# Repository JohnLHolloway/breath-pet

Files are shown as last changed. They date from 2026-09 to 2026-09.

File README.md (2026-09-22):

# Breath Pet

A pocket party aquarium for the **LILYGO T-Display-S3**. Pick a nickname, adopt a pet, and watch everyone's creatures swim around together. Wake them with an MQ-3 sample or a quick bubble game, collect silly outfits, and decorate the shared tank.

| The shared tank | Your pet and its belongings |
| --- | --- |
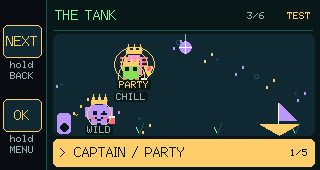
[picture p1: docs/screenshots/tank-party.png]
Three pets swimming with accessories and status labels
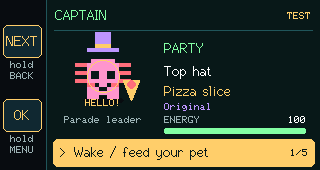
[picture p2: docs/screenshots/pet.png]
Pet detail with personality, outfit and one energy meter
|  |  |

**MQ-3 readings produce fictional game levels, not BAC or an estimate of intoxication.** A cup-vapor test works for setup without drinking. Clothes and rewards do not depend on getting a higher reading.

## Start playing

1. Hold the board landscape with **USB and the two front buttons on the left**.
2. Select **Add a pet**, pick a nickname, then a species. The tank starts empty and holds up to six pets.
3. Select your pet. **Wake / feed** starts a **5-second countdown**, then **10 seconds of BLOW**. Only the highest reading during BLOW determines the game reaction.
4. Watch its state in the tank, or open its detail page for History, Take a nap, Wardrobe and Play bubble catch.

Clean air is monitored in the background. Feed starts immediately when the signal is settled; **Sensor recovering** appears only if it needs more time. It starts the countdown automatically once ready, or you can cancel. The first window after power-up takes at least ten seconds. For cup testing, bring vapor near the dry sensor at BLOW and remove it when capture finishes.

| Physical button | Tap | Hold 1.2 seconds |
| --- | --- | --- |
| **Upper / BOOT / GPIO0** | NEXT: cycle the selection | Back / cancel |
| **Lower / GPIO14** | OK: choose the gold action | Evening menu |

The left rail corresponds to the physical buttons. Every selectable page uses the same gold action bar. During countdown and BLOW, taps are disabled; holds still cancel or open the menu. No touch controller was detected on the tested board; both buttons are sufficient. LILYGO sells standard and touch variants. Touch-controller support exists in firmware but has not been verified on touch hardware.

## What the pets do

- **CHILL, PARTY and WILD** change swimming and expressions. High readings cause no damage.
- After **10 powered minutes** without feeding or a completed game, pets become DROWSY; after **20**, they fall ASLEEP. Any completed sample, even level zero, or a three-catch game wakes them. There is one energy meter.
- Check in to find red cups, hats and other accessories, with at most one rewarded check-in per pet per ten powered minutes. Clothes and colours are collected during the current evening.
- Everyone contributes to a jukebox, pirate ship and disco ball. View Best Dressed, Most Naps and Social Butterfly in Evening awards.
- **Start new evening** asks for confirmation, then clears pets, readings, clothes, colours, awards progress and shared decorations. Sensor settings stay saved.

See the [gameplay guide](docs/GAMEPLAY.md) for reactions, rewards, persistence and all menu options, or browse the [current screen gallery](docs/screenshots/README.md).

## Wire the sensor

Use the module's **5 V supply, common ground, and AO through an equal-resistance voltage divider to GPIO1**. Eight 2 kΩ resistors make two 8 kΩ chains. Leave DO disconnected. Do not connect a 5 V output directly to the ESP32.

Follow the [wiring diagram and meter checks](MQ3_WIRING.md) before connecting the ADC input. **MQ-3 setup** retains the millivolt trace for diagnostics; normal play shows game levels and a response bar. Response settings adjust game sensitivity, not BAC calibration. Normal firmware boots in LIVE mode; Menu > Change input mode enables DEMO for the current boot.

## Build and upload

With Python and Git installed, run in PowerShell:

```powershell
git clone https://github.com/JohnLHolloway/breath-pet.git
cd breath-pet
.\dev.ps1 build
.\dev.ps1 upload -Port COM3
```

The helper creates a local Python environment and installs development tools. Replace COM3 with your board's port. Close any serial monitor before uploading. If connection fails, hold BOOT, press and release RST, release BOOT, then retry the upload.

[Development instructions](docs/DEVELOPMENT.md) cover other platforms, dependencies, serial commands, isolated device tests and screenshot capture. [Hardware verification](HARDWARE_TEST.md) records the tested board, the 105-check suite and what remains physically unverified.

## Screenshots and licensing

The gallery contains **actual 320 × 170 framebuffers exported by the ESP32**, using fictional pets and synthetic sensor inputs in isolated test firmware. TEST means test firmware, not a real person's reading. They are not photographs or a physical panel readback. The gallery includes a reproducible capture tool and a hash manifest.

Original code is MIT licensed. TFT_eSPI 2.5.43, TouchLib, the board definition and display initialization come from [LILYGO's T-Display-S3 repository](https://github.com/Xinyuan-LilyGO/T-Display-S3), commit `ec889e789b3cf093412689a143f7f37b42b56af7`; vendor licenses remain in `lib/`. LILYGO provides [factory firmware](https://github.com/Xinyuan-LilyGO/T-Display-S3/tree/main/firmware). No factory flash dump or private player readings are included.

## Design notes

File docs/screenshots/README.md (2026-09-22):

# Current screen gallery

[Project home](../../README.md) · [Gameplay](../GAMEPLAY.md) · [Wiring](../../MQ3_WIRING.md) · [Capture instructions](../DEVELOPMENT.md#screenshots)

Captured **2026-09-22** from firmware **version 8** on the LILYGO T-Display-S3. These are native **320 × 170 ESP32 framebuffer exports**, not photos or panel readback. The fixtures use fictional Captain, Goose and Bean pets in separate test storage. **TEST means isolated firmware; every sensor reading in this gallery is synthetic, including entries labeled MQ3.** Normal firmware instead labels its mode LIVE or DEMO.

The same left-side NEXT/OK rail and gold action bar are used throughout. Hold the upper button for Back and the lower for Menu. The gallery replaces older screenshots of the previous menus and multiple care bars.

The [capture manifest](manifest.json) records the source revision, firmware hash and image hashes. Regenerate it with `tools/capture_gallery.py` from the repository root; that script restores normal firmware and checks saved data before publishing images. Animation positions and randomly awarded accessories can differ on another run.

## Join an evening

| An empty evening: add pets one at a time. | Choose an unused nickname. |
| --- | --- |
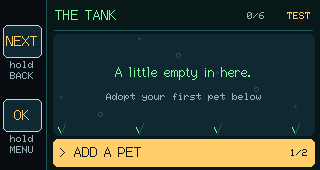
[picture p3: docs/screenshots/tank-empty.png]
An empty evening: add pets one at a time.
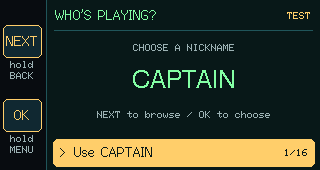
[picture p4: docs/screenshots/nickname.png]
Choose an unused nickname.
|  |  |

| Choose one of six species. | Optional DEMO picker; normal firmware starts in LIVE mode. |
| --- | --- |
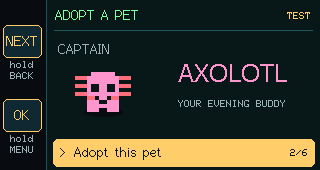
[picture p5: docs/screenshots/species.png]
Choose one of six species.
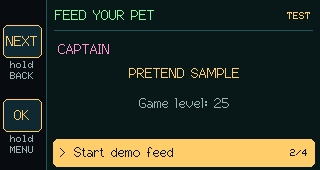
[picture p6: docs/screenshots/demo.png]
Optional DEMO picker; normal firmware starts in LIVE mode.
|  |  |

## Pets in the shared tank

| Three pets swim freely with reactions, accessories and shared decorations. | PARTY, DROWSY and sleeping pets share the same tank. |
| --- | --- |
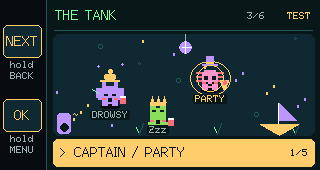
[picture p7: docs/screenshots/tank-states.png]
PARTY, DROWSY and sleeping pets share the same tank.
| Three pets swim freely with reactions, accessories and shared decorations. |  |

| Pet detail: personality, equipped belongings and one energy meter. | Cycle unlocked hats, hand items and colours. |
| --- | --- |
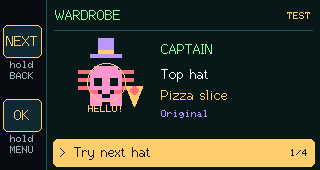
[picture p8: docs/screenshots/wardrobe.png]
Cycle unlocked hats, hand items and colours.
| Pet detail: personality, equipped belongings and one energy meter. |  |

## Wake and play

| Catch three bubbles in the gold zone to wake your pet. | Five seconds to get ready; the peak window has not started. |
| --- | --- |
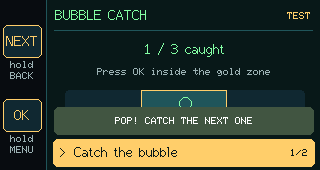
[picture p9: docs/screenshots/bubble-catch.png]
Catch three bubbles in the gold zone to wake your pet.
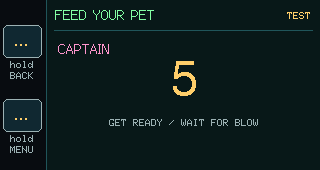
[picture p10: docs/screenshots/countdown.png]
Five seconds to get ready; the peak window has not started.
|  |  |

| Ten seconds of BLOW with a game-response meter, using injected 850 mV. | Level 60 / PARTY from the synthetic MQ-3 capture; this is not BAC. |
| --- | --- |
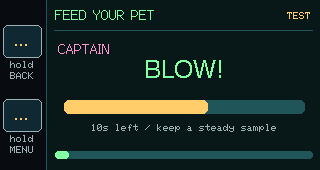
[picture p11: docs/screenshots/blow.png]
Ten seconds of BLOW with a game-response meter, using injected 850 mV.
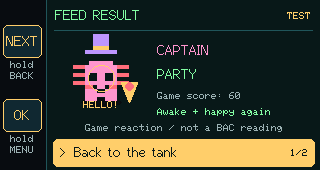
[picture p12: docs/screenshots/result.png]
Level 60 / PARTY from the synthetic MQ-3 capture; this is not BAC.
|  |  |

## Readings and controls

| Per-pet readings show level and source; older DEMO samples stay labeled. | Recovery appears only when Feed is requested before the signal settles. |
| --- | --- |
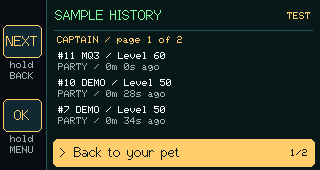
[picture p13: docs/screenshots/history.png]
Per-pet readings show level and source; older DEMO samples stay labeled.
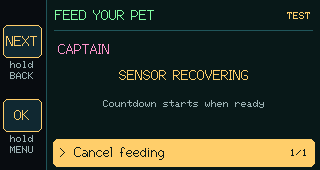
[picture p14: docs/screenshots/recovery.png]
Recovery appears only when Feed is requested before the signal settles.
|  |  |

| The evening menu uses the same selector and physical-button labels. | Adjust game sensitivity; these settings do not calibrate BAC. |
| --- | --- |
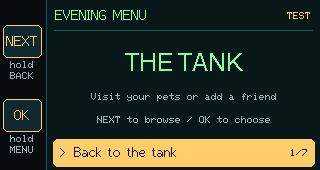
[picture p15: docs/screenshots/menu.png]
The evening menu uses the same selector and physical-button labels.
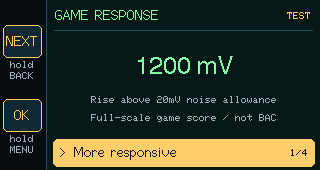
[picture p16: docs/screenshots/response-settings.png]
Adjust game sensitivity; these settings do not calibrate BAC.
|  |  |

## Setup and evening progress

| Bench diagnostics retain millivolts and a trace; this fixture injects 100 mV. | Evening awards summarize clothing, naps and friendly encounters. |
| --- | --- |
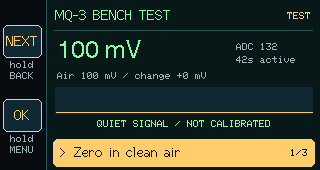
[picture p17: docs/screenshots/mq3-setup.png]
Bench diagnostics retain millivolts and a trace; this fixture injects 100 mV.
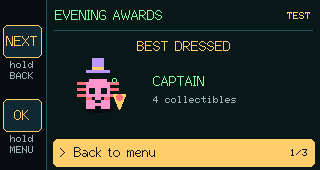
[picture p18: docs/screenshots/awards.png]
Evening awards summarize clothing, naps and friendly encounters.
|  |  |

| Shared decorations last for this evening and reset with a new one. | Keep is the default; resetting clears pets, readings, clothes and decorations. |
| --- | --- |
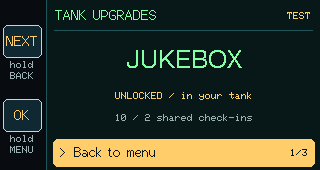
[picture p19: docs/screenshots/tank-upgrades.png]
Shared decorations last for this evening and reset with a new one.
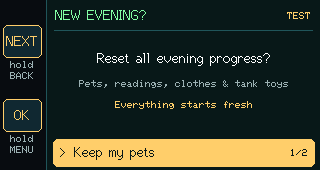
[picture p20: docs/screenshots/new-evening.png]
Keep is the default; resetting clears pets, readings, clothes and decorations.
|  |  |

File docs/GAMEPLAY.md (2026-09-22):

# Gameplay guide

[Project home](../README.md) · [Screen gallery](screenshots/README.md) · [Wiring](../MQ3_WIRING.md)

## Adopt a pet

An evening starts with an empty tank. Choose Add a pet, an unused nickname, then a species. Add people individually, up to six. NEXT cycles; OK confirms. The tank selector cycles through occupied pets, Add a pet if space remains, and Menu. A gold ring marks the selected swimmer, and the bottom bar gives its name and full state. All pets move in the same tank.

The built-in nickname picker offers Captain, Goose, Bean, Chaos, Pickle, Nugget, Bubbles, Spud, Mochi, Gremlin, Waffles, Noodle, Goblin, Peach, Squid and Biscuit. Used names are skipped. Species are Blob, Axolotl, Bat, Cat, Ghost and Frog. Custom 1–8-character alphanumeric names can be added through USB; there is no on-device keyboard.

## Feed and read a reaction

In LIVE mode, choose a pet and press OK on Wake / feed:

1. **GET READY — 5 seconds.** The recent clean-air average is frozen as the baseline. This phase does not collect a peak.
2. **BLOW — 10 seconds.** Provide the sample now. The highest accepted reading in this window sets the level; the screen shows a response bar.
3. **Result.** See the game level and reaction, then return to the tank or visit the pet. One completed sample adds one entry to that pet's history.

The sensor runs in the background on every LIVE screen. The game uses the nominal clean-air band to decide readiness and the recent average for the actual baseline; it does not assume a fixed voltage. Normally there is no separate clean-air step. If Feed is requested before the signal settles, Sensor recovering waits and automatically starts the countdown once ready. OK or Back cancels that pending request. After power-up or switching to LIVE, the first window takes at least ten seconds.

Hold the upper button to cancel a countdown or capture; hold the lower button to open the menu. Cancelling saves no reading. Invalid captures show an explicit retry action and do not restart themselves. A five-second feed cooldown prevents repeated submissions; previously fed pets also have this short cooldown after reboot.

In DEMO mode, Wake / feed first offers fake values 0, 25, 50 and 85, then uses the same countdown and capture timing. Choose Change input mode in the evening menu to switch. Normal firmware returns to LIVE after reboot.

### Game sensitivity

These are provisional **game thresholds**, not BAC or intoxication estimates. All millivolt values refer to **GPIO1 after the divider**, not the module's AO pin.

| Setting | Current behavior |
| --- | --- |
| Clean-air readiness | Rolling 100-sample window, at least 10 seconds; every reading 50–250 mV; spread at most 25 mV |
| Baseline | Mean of that window, frozen when GET READY begins |
| Response gate | Peak below 400 mV gives level 0 |
| Default response span | 1200 mV; saved custom settings survive firmware updates |
| Response settings | Change span by 100 mV, within 100–2000 mV; a smaller span gives a higher level for the same rise |
| Capture rejection | Any BLOW sample below 20 or above 2700 mV, or fewer than 80 acquired samples |

For a peak of at least 400 mV:

```text
level = clamp(max(0, peak_mV - baseline_mV - 20) * 100 / span_mV, 0, 100)
```

For example, baseline 100 mV and peak 850 mV at the default span yield level 60 (integer arithmetic). The 400 mV gate is a minimum response gate, not the start of PARTY: a 400 mV peak with a 100 mV baseline gives level 23 / CHILL.

A quiet completed capture is deliberately accepted as level zero and wakes the pet. The sensor does not detect airflow or establish that someone blew. A cup test demonstrates response and recovery, not concentration calibration. [Wiring and bench testing](../MQ3_WIRING.md) explain the separate diagnostic baseline.

## State and energy

| State | Trigger and appearance |
| --- | --- |
| CHILL | Level 0–24: gentle swimming and bubbles |
| PARTY | Level 25–69: livelier swimming and more bubbles |
| WILD | Level 70–100: zooming, winking, wobbling and sparkles |
| DROWSY | 10 powered minutes since the last feeding or completed game |
| ASLEEP | 20 powered minutes, or Take a nap: closed eyes and Zzz on the tank floor |

A completed sample of **any level**, or a completed bubble game, resets idle time, restores energy to 100 and plays a wake-up animation. Energy decreases by five per powered minute. Sleep overrides the reaction label until the pet wakes. There is no neglect damage or high-reading penalty. Timers pause when powered off; they are not a wall clock. Take a nap has a ten-second button cooldown.

The tank shows each pet's compact state label, with Zzz for sleepers. The pet page shows its personality, equipped hat/item/colour and **one energy bar**. Old health, food and joy fields remain in storage and USB diagnostics for compatibility; they are no longer separate care meters in the UI.

## Pet actions

| Action | What it does |
| --- | --- |
| Wake / feed | Run a LIVE capture or choose a DEMO value |
| History | Browse the pet's last 16 readings, three per page; NEXT changes page, OK returns |
| Take a nap | Put the pet to sleep immediately |
| Wardrobe | NEXT selects Hats, Hand items, Colours or Back; OK cycles unlocked choices |
| Play bubble catch | Press OK while the moving bubble is in the gold zone; three catches win and wake the pet; NEXT selects Back |

History on the device shows level, source, reaction and age. USB history also includes original baseline, peak and response span for MQ3 entries. Old DEMO entries remain DEMO and old saved health deltas are preserved. Changing sensitivity does not rewrite earlier scores. A bubble-game win does not create a sensor-history entry.

## Clothes and personalities

A completed feeding or bubble game earns at most **one rewarded check-in per pet per ten powered minutes**. Extra play or feeding still wakes the pet but earns no extra loot. Sensor level never determines reward eligibility or which item is awarded.

- If the nickname has never collected a red cup, its first rewarded check-in supplies and equips one.
- Later eligible check-ins choose a random unowned hat, hand item or colour. The third rewarded check-in of an evening guarantees a hat if any remain locked. New accessories equip automatically.
- Hats: party cone, cowboy hat, crown, sunglasses and top hat. Hand items: red cup, pizza slice, floatie and bubble wand. Wardrobe also allows no hat or no hand item.
- Sunshine, lilac and ocean colours can be earned through eligible check-ins during the evening. Rebooting keeps collections; starting a new evening clears every nickname collection.

Personalities are stable by nickname. Captain leads parades, Goose plays hat pranks, and Bean is a shy cup buddy; other names get repeatable personalities. Non-sleeping pets periodically gather for a greeting or parade. A borrowed visual hat does not transfer inventory. Friendly encounters accumulate for a pair every two powered minutes when at least two pets are not ASLEEP; DROWSY pets can participate.

## Shared tank and evening menu

Shared rewarded check-ins unlock the jukebox at **2**, pirate ship at **5**, and disco ball at **8**. These totals and decorations reset with a new evening. An eligible check-in can unlock the disco ball early and trigger 15 seconds of confetti when there are at least two pets, every pet has checked in this evening, and everyone has been active within the last ten powered minutes.

| Evening menu option | Purpose |
| --- | --- |
| Back to tank | Return to the shared aquarium |
| Response settings | Adjust game sensitivity or restore the default; DEMO has separate fake-value zero/span settings |
| Start new evening | Confirm before clearing all evening progress, including clothes and decorations; Keep is the default |
| MQ-3 setup | Inspect voltage, ADC counts, trend and a temporary diagnostic baseline |
| Change input mode | Switch LIVE / DEMO for this boot |
| Evening awards | NEXT cycles Best Dressed, Most Naps and Social Butterfly; OK returns |
| Tank upgrades | NEXT browses the three shared decorations; OK returns |

Best Dressed counts cosmetics collected during this evening. Most Naps and Social Butterfly use this evening's naps and friendly encounters. Ties are identified. Awards update during play; view them before starting a new evening. There is no automatic awards archive.

## What gets saved

Pets, their individual histories, sensitivity settings, collected/equipped items, current party stats and shared upgrades survive restart. A new evening clears all active pets, readings, nickname collections (including equipped clothes and colours), evening stats, reward timers, shared progress and decorations. Returning nicknames start fresh. Device sensitivity settings are retained. Removing power does not simulate time passing. The LIVE/DEMO choice and temporary bench zero are not retained across reboot.

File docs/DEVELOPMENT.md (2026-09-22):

# Development

[Project home](../README.md) · [Gameplay](GAMEPLAY.md) · [Verification record](../HARDWARE_TEST.md)

## Toolchain and board

The target is the LILYGO T-Display-S3, ESP32-S3 with 16 MB flash, 8 MB OPI PSRAM and a 320 × 170 ST7789 parallel display. The build pins `espressif32@6.5.0` / Arduino-ESP32 2.0.14. Python development dependencies are pinned in `requirements-dev.txt`; display/touch libraries are vendored in `lib/`.

| Function | GPIO |
| --- | --- |
| Display power / backlight | 15 / 38 |
| Upper NEXT/BOOT / lower OK button | 0 / 14 |
| MQ-3 divided analog input | 1 / ADC1_CH0 |
| Optional touch SDA / SCL / reset / interrupt | 18 / 17 / 21 / 16 |

Landscape orientation uses display rotation 3, placing USB and buttons on the left. Firmware probes CST816-family address `0x15` and CST328 address `0x1A`. No controller was detected on the tested board; touch support is unverified on actual touch hardware.

## Build, upload and monitor

On Windows, with Python and Git installed:

```powershell
.\dev.ps1 build
.\dev.ps1 upload -Port COM3
.\dev.ps1 monitor -Port COM3
```

The helper creates `.venv` and installs requirements on first use. After pulling changed dependencies into an existing checkout, update them explicitly:

```powershell
.venv\Scripts\python.exe -m pip install -r requirements-dev.txt
```

If PowerShell blocks scripts, use a per-invocation override such as `powershell -ExecutionPolicy Bypass -File .\dev.ps1 build`. Ctrl+C exits the monitor; close it before any upload, test or capture because each needs exclusive serial-port access. To list ports, run `.venv\Scripts\python.exe -m platformio device list`.

If upload cannot connect, hold BOOT, press/release RST, release BOOT, and retry. If needed, unplug USB, hold BOOT while reconnecting, then release it. The port may change; check again. Press RST after upload if the application does not start.

On Linux/macOS:

```sh
python3 -m venv .venv
. .venv/bin/activate
python -m pip install -r requirements-dev.txt
python -m platformio run -e breath-pet
python -m platformio run -e breath-pet -t upload --upload-port /dev/ttyACM0
```

Replace the example port for your system and ensure serial-device access. `.pio/`, `.cache/platformio/` and `.venv/` are local and ignored by Git.

## Isolated tests

With the board attached and serial monitor closed:

```powershell
.\dev.ps1 test -Port COM3
```

This builds/flashes `device-test`, runs `tools/test_device.py --reset-demo-data`, and restores `breath-pet` in a `finally` block even when a test fails. Keep USB connected. If restoration fails, run `dev.ps1 upload` again. Normal firmware boots LIVE; test firmware boots DEMO.

| Saved data | Normal firmware | Test firmware |
| --- | --- | --- |
| Roster, histories, calibration | `breath-pet` | `breath-test` |
| Nickname collections, party progress | `pet-fun` | `fun-test` |

The runner refuses its reset unless the device reports `test_mode: true`. `-ResetDemoData` on the PowerShell helper is retained for compatibility but is not required. The latest device suite has **105 checks**, covering navigation, capacity, owner isolation, persistence, rolling baseline/recovery, five-plus-ten-second capture, rejection/cancellation, sleep, game wins/misses, loot timing, wardrobe, awards, colour rewards and complete evening resets (including restart persistence). `selftest` adds firmware-side rule, migration and ring-buffer checks. See [hardware verification](../HARDWARE_TEST.md) for the scope and limits of the result. The full private run report goes to ignored `test-results.json`.

Test firmware alone accepts ADC injection, accelerated game time and a fixed bubble position. Advancing game minutes does **not** skip real-time feed or nap button cooldowns. These commands are absent from normal builds:

| Command | Test-only effect |
| --- | --- |
| `test sensor 100` | Inject a chosen integer ADC millivolt value, 0–999 |
| `test sensor high` | Inject 2900 mV for rejection checks |
| `test sensor off` | Resume physical ADC readings |
| `test minutes 10` | Advance the powered game clock |
| `test bubble 50` | Fix bubble position, 0–100; 50 is a catch, 0 a miss |
| `test fun reset` | Reset isolated collections/progress |

## Screenshots

Capture one current screen without switching firmware:

```powershell
.venv\Scripts\python.exe tools\capture_screen.py artifacts\tank.png --port COM3 --command tank
```

Repeated `--command` arguments navigate before capturing. Avoid commands that create normal readings if you are only reviewing layout. This exports the rendered framebuffer, not a camera photo or panel readback.

To regenerate the public gallery:

```powershell
.venv\Scripts\python.exe tools\capture_gallery.py --port COM3
```

Start with **normal firmware** on the board. The script:

1. Saves a private normal-state snapshot under ignored `artifacts/gallery/`.
2. Flashes isolated test firmware, verifies its mode, resets only test data, and creates fictional pets through game commands.
3. Captures the current pages, using synthetic ADC values for sensor screens.
4. Restores normal firmware in `finally`, checks the normal roster, exact histories, sensitivity, equipped/owned items and key stats against the snapshot, and checks both save areas.
5. Publishes the successful PNG set and `manifest.json` under `docs/screenshots/` only after restoration and verification succeed.

A failed or interrupted run still attempts restoration; a disconnected board may need a manual upload. The script leaves the normal board on the tank. Private normal snapshots and upload logs are never copied into the gallery. It replaces isolated test pets/collections and does not preserve a previous test fixture.

All public screenshots are 320 × 170 actual device frames. The manifest records timestamp, firmware version, source commit, test binary SHA-256 and individual image SHA-256 values. Capture time, random accessory rewards and animation frames may differ between runs. **TEST** indicates isolated firmware; an MQ3 source label in a gallery image uses injected values, not a real person's reading. Review the images visually and update [gallery captions](screenshots/README.md) when the UI changes. Remove superseded images and broken references before publishing.

## Serial protocol

Use newline-terminated UTF-8 commands at **115200 baud**. Unsolicited status JSON is emitted periodically. Commands can be prefixed with an integer request ID, for example `@123 status`. The device acknowledges with `CMD 123`, and JSON replies echo `request_id: 123`; unsolicited JSON has ID zero. Match IDs and accumulate partial lines before parsing. If an action's reply is lost, recover with a read-only status/history query rather than repeating the action.

| Commands | Behavior |
| --- | --- |
| `status`, `history` | State JSON; selected pet's full stored reading metadata |
| `selftest`, `touchscan` | Firmware rule checks; diagnostic I2C scan |
| `join CAPTAIN 1` | Add an unused 1–8-character alphanumeric name and species 0–5 |
| `select 0`, `tank` | Open an occupied slot 0–5 or return to tank |
| `ui next`, `ui select`, `ui back`, `ui menu` | Drive the same navigation handlers as the physical controls |
| `sample 25` | Instant fake capture, 0–100, in DEMO only; observes feed cooldown |
| `rest` | Nap the selected pet; observes nap cooldown |
| `input live`, `input demo` | Switch input for this boot |
| `cal default`, `cal minus`, `cal plus` | Restore or adjust the active mode's response span |
| `cal zero` | Set fake-value zero in DEMO; rejected in LIVE |
| `sensor open`, `sensor zero`, `sensor clear` | Bench screen and independent temporary diagnostic baseline |
| `night new CONFIRM` | Clear this evening's roster/history; retain collections/upgrades |
| `screen` | Binary framebuffer export |
| `reboot`, `help` | Restart; print supported normal commands |

LIVE baseline capture is automatic. `sensor zero` does not alter gameplay sensitivity or readiness. History includes source (`MQ3` or `DEMO`), score, original raw value, baseline/peak/span, boot/uptime and legacy health delta. Do not interpret game levels as BAC.

`screen` emits `FRAME 320 170 RGB565BE`, a newline, then 108800 binary bytes (big-endian RGB565). The payload is followed by a newline and `END_FRAME`. Read exactly that many bytes before returning to line-oriented parsing; `tools/capture_screen.py` handles conversion to PNG.

## Source and persistence

| File | Responsibility |
| --- | --- |
| `src/main.cpp` | Navigation, input, feed timing and serial protocol |
| `src/ui.h` | Tank animation, creatures, shared controls and screen rendering |
| `src/party.h` | Per-player state, ring-buffer history, calibration and save migration |
| `src/fun.h` | Energy/sleep, collections, rewards, personalities, decorations and awards |
| `src/mq3.h` | ADC acquisition, rolling window, capture and rejection checks |
| `src/hardware.h` | Display setup, button debouncing and touch input |
| `tools/test_device.py` | Device integration suite |
| `tools/capture_screen.py`, `tools/capture_gallery.py` | Single frame and isolated gallery capture |

Current party state uses the versioned `party-v2` record; collections/progress use a separate `fun-v1` record. Startup removes an obsolete `party-v1` key **only after validating the v2 record**, reclaiming space in the 20 KB NVS partition. Do not erase or format NVS as routine troubleshooting. A changed party evening ID resets the entire fun record, including all nickname collections and shared progress. This also completes the reset on startup if power was lost between the two saves. Matching IDs preserve progress on reboot. Normal and test namespaces must remain separate. `storage_ok` and `fun_storage_ok` in status report save health.

Keep `.env`, flash dumps, local logs, private snapshots and real player readings out of commits. Documentation screenshots must use fictional isolated fixtures.

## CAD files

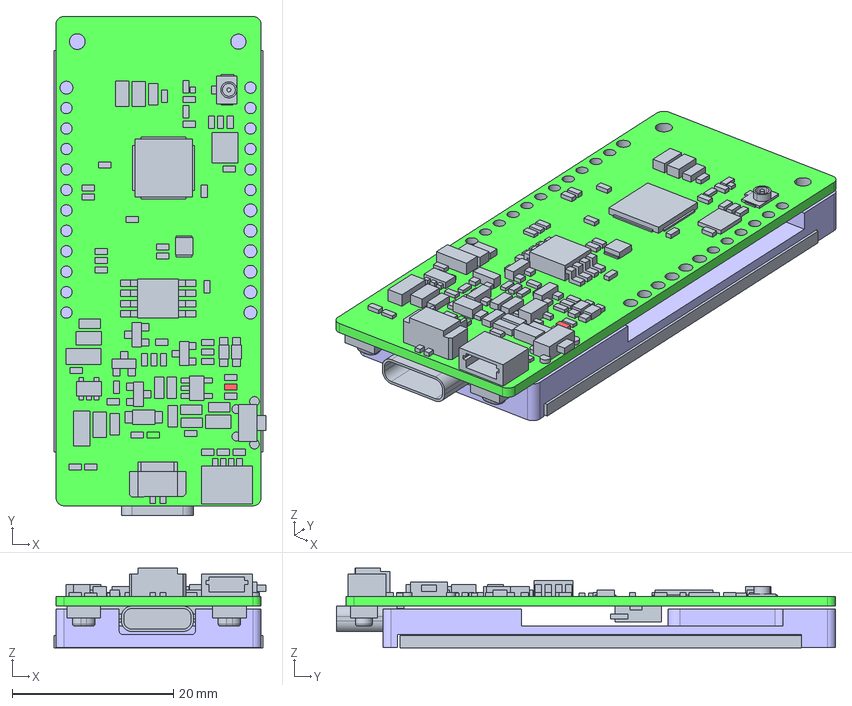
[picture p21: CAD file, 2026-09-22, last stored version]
hardware/reference/t-display-s3-full.step
26.3 x 62.0 x 9.88 mm
T_DISPLAY_S3
LCD-NFP190B
K20430001

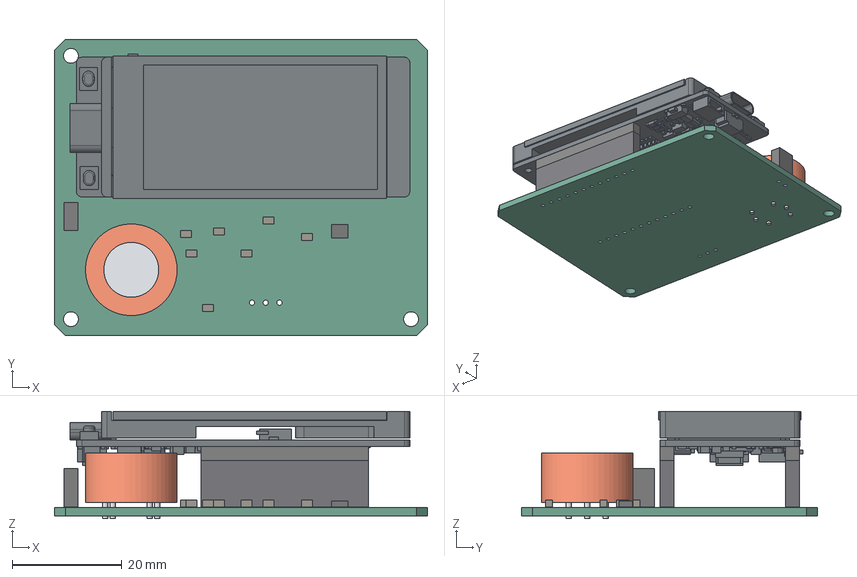
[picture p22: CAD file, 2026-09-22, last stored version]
hardware/rev-a/mechanical/electronics-assembly.step
68.0 x 54.0 x 19.5 mm
carrier
display-board
sensor-measured-envelope
sensor-mesh-placeholder
diode
power-jumper
socket-0
socket-1
header-spacer-0
header-spacer-1
lead-0
lead-1
lead-2
lead-3
lead-4
lead-5
smd-0
smd-1
smd-2
smd-3
smd-4
smd-5
smd-6

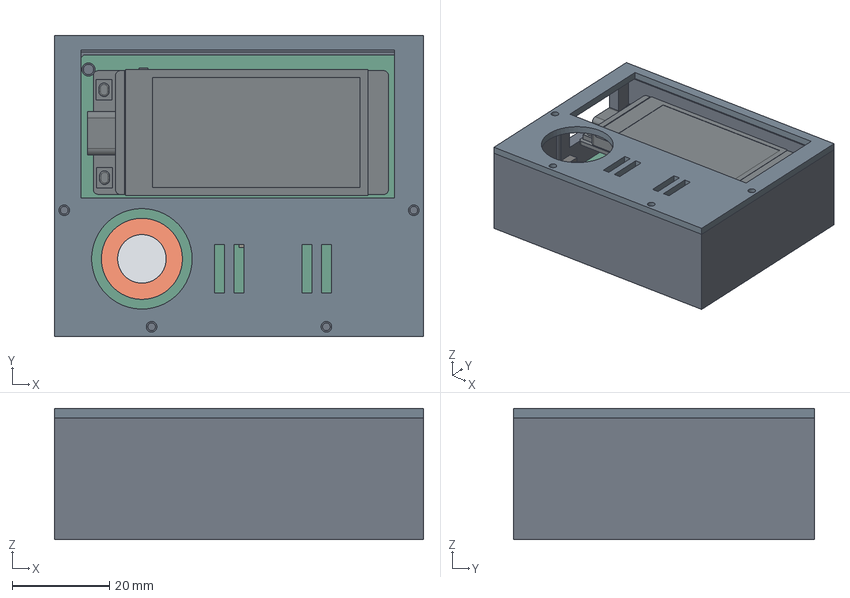
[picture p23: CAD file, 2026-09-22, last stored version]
hardware/rev-a/mechanical/case-assembly.step
76.0 x 62.0 x 27.0 mm
base
cover
carrier
display-board
sensor-measured-envelope
sensor-mesh-placeholder
diode
power-jumper
socket-0
socket-1
header-spacer-0
header-spacer-1
lead-0
lead-1
lead-2
lead-3
lead-4
lead-5
smd-0
smd-1
smd-2
smd-3
smd-4
smd-5
smd-6

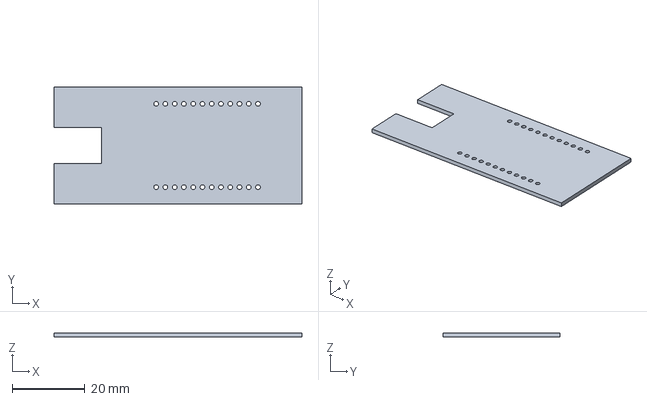
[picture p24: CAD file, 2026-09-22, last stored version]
hardware/rev-a/mechanical/header-fit-gauge.step
68.0 x 32.0 x 1.20 mm

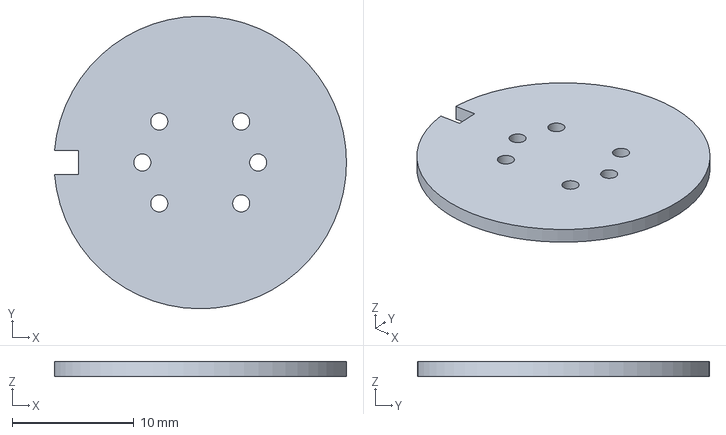
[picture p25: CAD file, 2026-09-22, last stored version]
hardware/rev-a/mechanical/sensor-fit-gauge.step
24.0 x 24.0 x 1.20 mm

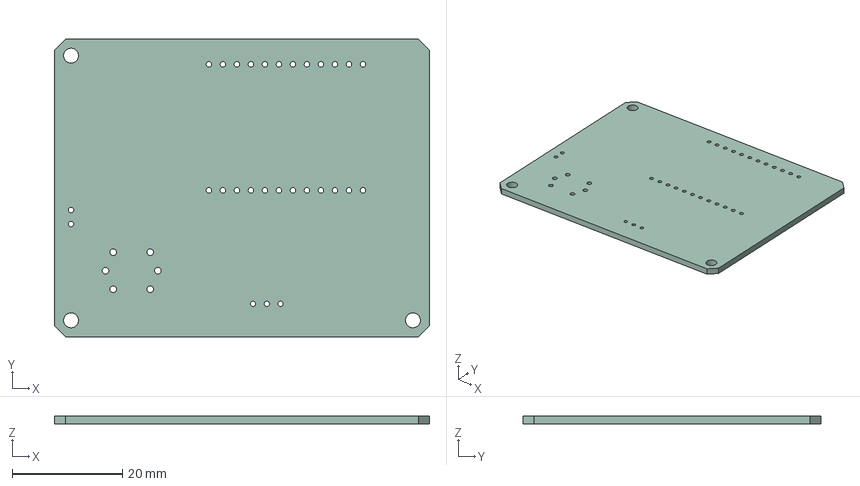
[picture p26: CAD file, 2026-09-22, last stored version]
hardware/rev-a/mechanical/carrier-board.step
68.0 x 54.0 x 1.51 mm

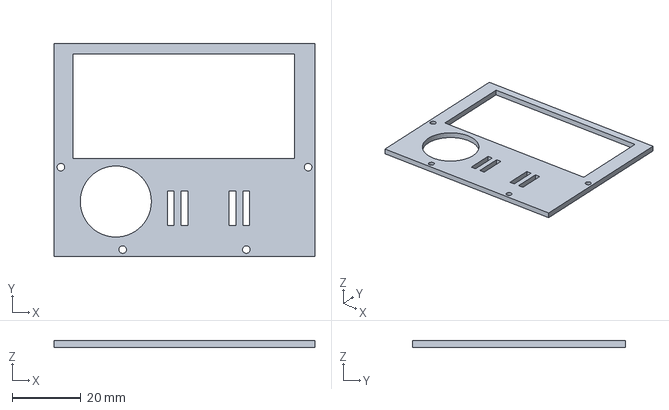
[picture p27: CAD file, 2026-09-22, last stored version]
hardware/rev-a/mechanical/case-cover.step
76.0 x 62.0 x 2.00 mm

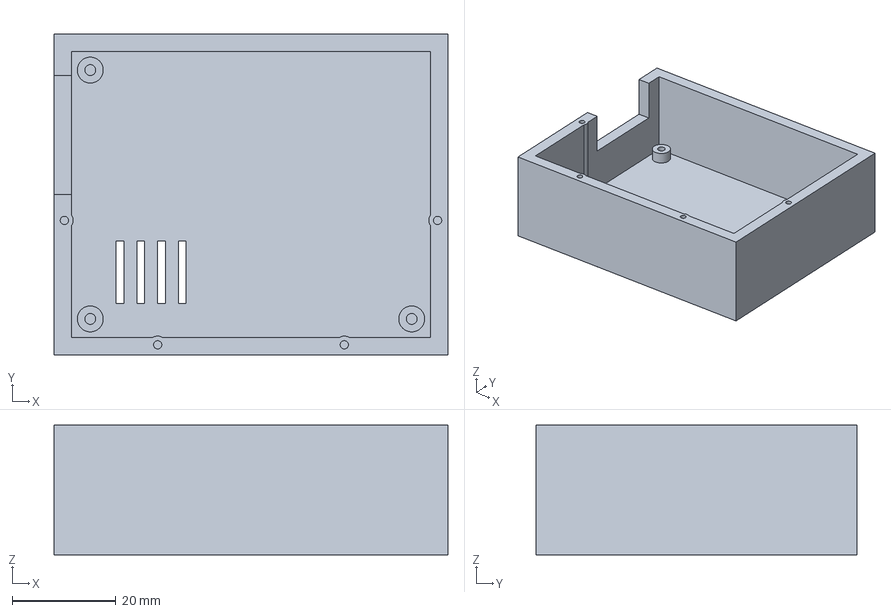
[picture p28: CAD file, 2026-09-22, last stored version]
hardware/rev-a/mechanical/case-base.step
76.0 x 62.0 x 25.0 mm

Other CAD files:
hardware/rev-a/mechanical/case-base.stl
hardware/rev-a/mechanical/case-cover.stl
hardware/rev-a/mechanical/header-fit-gauge.stl
hardware/rev-a/mechanical/sensor-fit-gauge.stl

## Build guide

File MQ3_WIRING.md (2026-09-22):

# MQ-3 wiring and bench testing

[Project home](README.md) · [Gameplay and thresholds](docs/GAMEPLAY.md) · [Hardware verification](HARDWARE_TEST.md)

This USB-powered setup uses an ACEIRMC MQ-3 module, a LILYGO T-Display-S3 and **eight 2 kΩ resistors**. A ninth resistor can remain spare. Follow the labels on your actual boards; the diagram is a logical connection map, not header order.

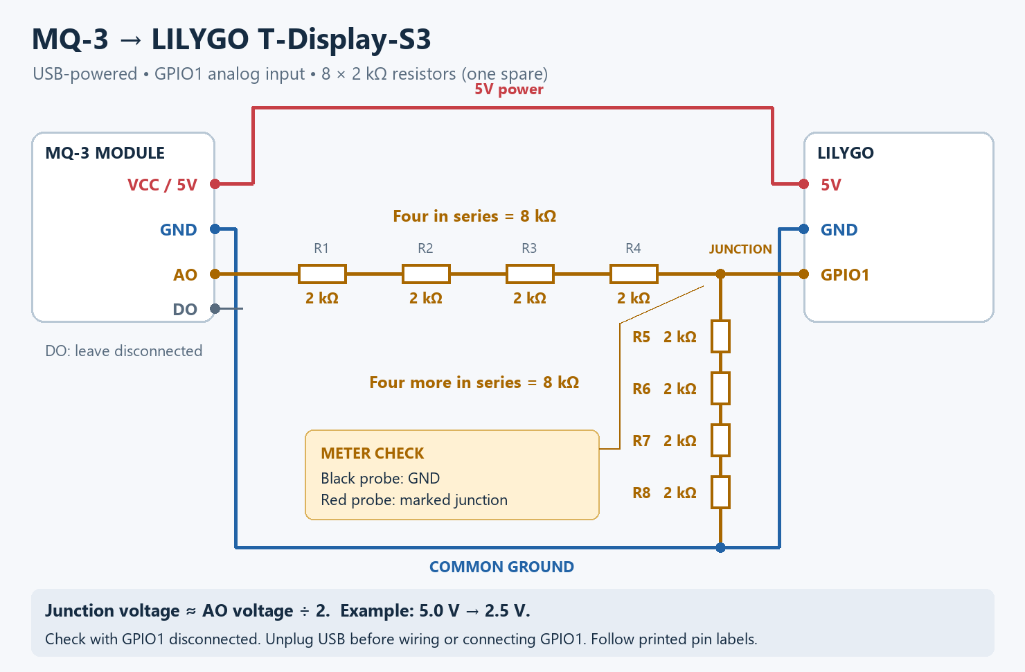
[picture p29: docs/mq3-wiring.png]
MQ-3 to LILYGO: 5 V supply, common ground and an eight-resistor divider to GPIO1


Dots mark connections. Crossings without dots are not connected.

## Connections

Power off before changing wiring. Four 2 kΩ resistors in series make the upper 8 kΩ chain; four more make the lower 8 kΩ chain.

| MQ-3 module pin | Connection |
| --- | --- |
| VCC | LILYGO **5V**, with the board powered by USB |
| GND | LILYGO **GND**, shared with the bottom of the divider |
| AO | Upper resistor chain, then the divider junction to **GPIO1** |
| DO | Leave disconnected |

```text
MQ-3 AO -- 2k -- 2k -- 2k -- 2k --+-- GPIO1 (ADC1_CH0)
                                 |
                                 +-- 2k -- 2k -- 2k -- 2k -- GND
```

Equal resistor chains divide the voltage by two: an ideal 5.0 V AO signal becomes 2.5 V at GPIO1. **Never connect AO or DO directly to an ESP32 input.** The sensor's heater takes 5 V power, not a GPIO or the 3V pin. Use the printed board labels and [LILYGO's board documentation](https://github.com/Xinyuan-LilyGO/T-Display-S3) to locate the header pins. This guide does not establish that battery-only operation supplies the module's 5 V requirement.

The firmware uses 12-bit ADC readings and 11 dB attenuation. Espressif documents an approximate 0–3.1 V measurable range for the ESP32-S3 at that attenuation; it does not make the input 5 V tolerant. [ADC documentation](https://docs.espressif.com/projects/arduino-esp32/en/latest/api/adc.html)

A typical four-band 2 kΩ resistor is red–black–red plus a tolerance band, often gold. Check resistance with a meter if the value is uncertain; five-band codes are read differently. The [module purchase listing](https://www.amazon.com/dp/B0978KZQVY) identifies the selected module, but follow its printed pin labels rather than assuming the photographed order.

## Verify the divider

1. Unplug USB and leave the junction disconnected from GPIO1 while assembling the divider.
2. Power the board/module by USB. In DC voltage mode, put the black probe on common GND.
3. Measure AO and the junction. The junction should be approximately **half of AO** and no higher than about **2.6 V** in this nominal 5 V setup. If it is not, disconnect power and inspect the connections.
4. If both points read zero, that alone does not verify the divider. With power removed, check the two resistor chains, or test the isolated divider against a known 5 V source while GPIO1 remains disconnected.
5. Unplug USB, connect the verified junction to GPIO1, then power up again.

The heater normally gets hot. Keep the sensor dry and clear of loose wires; do not immerse it or let liquid contact it. Physical voltage-divider measurements have not yet been recorded for the tested assembly. Observing an ADC response does not replace this electrical check.

## Bench screen

Hold the lower button for the evening menu, then select **MQ-3 setup**. The screen shows GPIO1 millivolts, raw ADC counts, a 0–3100 mV trend graph and elapsed **acquisition-active time**. In LIVE mode the timer can predate opening the screen; it is not a heater warm-up timer.

The ADC averages four conversions every 100 ms. In LIVE mode acquisition continues on every screen, retaining the rolling window when you navigate. In DEMO it runs only on the bench screen; reopening that screen starts a fresh window.

NEXT cycles **Zero in clean air**, **Clear air baseline** and **Back to menu**. OK performs the action. Zero accepts a temporary diagnostic baseline only after 100 samples, with a latest reading of 50–2700 mV and a window spread of at most 50 mV. Once set, the screen shows the difference from that window average. Rebooting clears the bench zero. In LIVE mode navigation preserves it; in DEMO reopening the bench resets it.

**Bench zero is independent of feeding.** It does not change the game baseline, clean-air band or sensitivity. The bench's wider acceptance range is useful for diagnostics; a quiet bench trace does not automatically mean Feed is ready. Feeding requires every reading in the window to be 50–250 mV, with at most 25 mV spread.

## Test with cup vapor

No drinking is needed to check sensor response.

1. Let the powered sensor settle in clean air. Watch the trace on MQ-3 setup.
2. Bring a cup of beer, wine or sake near the dry sensor so vapor can reach it, without contact with the liquid. Observe the rise, then remove the cup and watch recovery.
3. To record a game sample, select a pet and choose **Wake / feed**. A ready background window starts GET READY immediately; otherwise Sensor recovering waits automatically.
4. Wait through the **five-second countdown**. Bring vapor near the sensor only at **BLOW**, which lasts **ten seconds**. Remove the cup when the result appears.
5. Check the pet's History. The entry is labeled MQ3. Recovery continues while you browse; a new feeding waits only when needed.

Keep cups away during baseline collection. Neither cup vapor nor ordinary breath establishes a BAC scale: humidity and exposure distance also affect response. The current thresholds are game settings. See the [gameplay guide](docs/GAMEPLAY.md#game-sensitivity) for the 400 mV gate, default 1200 mV span and exact score formula. All app voltages are measured after the divider at GPIO1.

A new sensor also needs conditioning before repeatable comparisons. The Winsen MQ-3 manual specifies more than 48 hours of preheat under its standard test conditions. The exact sensing element in a reseller module has not been verified; use its own datasheet when available. A quiet ten-second trace is not a substitute for conditioning. [Winsen MQ-3 manual](https://cdn.sparkfun.com/datasheets/Sensors/Biometric/MQ-3%20ver1.3%20-%20Manual.pdf)

## Troubleshooting

| Symptom | Check |
| --- | --- |
| Sensor recovering immediately after startup | Allow the first full ten-second window to fill |
| Recovery continues after exposure | Remove the cup and allow the entire rolling window to return to 50–250 mV with no more than 25 mV spread |
| Low input / no response | Check power, common ground, AO wiring and the divider with a meter |
| High input | Disconnect power and inspect the divider before reconnecting GPIO1 |
| Level zero despite a small rise | Peaks below 400 mV intentionally score zero; a zero-level sample still wakes the pet |
| Level reaches 100 too easily | In Response settings, increase the span; this changes game sensitivity only |
| A rejected capture | No history or reward was saved; correct the signal and explicitly retry |
| Bench zero works but Feed waits | Bench zero and feeding use different readiness limits |

Cup testing has demonstrated qualitative response, recovery and stored samples. See the [verification record](HARDWARE_TEST.md) for what was physically observed versus tested with synthetic ADC values.

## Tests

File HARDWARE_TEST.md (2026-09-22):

# Hardware verification

Status: **2026-09-22, firmware version 8**. [Project home](README.md) · [Development](docs/DEVELOPMENT.md) · [Current gallery](docs/screenshots/README.md)

## Current evidence

| Area | Evidence | Scope |
| --- | --- | --- |
| Build and flash | Normal and isolated test firmware built/uploaded successfully; upload flash hashes verified | LILYGO T-Display-S3, ESP32-S3 revision 0.2, 16 MB flash, 8 MB PSRAM |
| Device integration suite | **105 / 105 checks passed**, run timestamp `2026-09-22T19:56:15.715273+00:00` | Latest firmware source; includes synthetic ADC and accelerated game time |
| Firmware self-test | Passed in isolated device suite | Rule boundaries, migration, history rollover, colour rewards and full evening reset |
| Physical display/buttons | User confirmed the displayed pet and both buttons | Current screen layout was additionally reviewed via framebuffer exports |
| Touch | No controller responded to probes or a full I2C scan | Operation on a touch-equipped variant remains unverified |
| Physical MQ-3 response | Cup vapor caused a rise and recovery; real-source history was saved | Qualitative response only, not concentration/BAC calibration |
| Background baseline | Physical sensor started a queued countdown at a 113 mV baseline; a subsequent request started immediately | Both attempts cancelled before BLOW, without creating history |
| Current gallery | **20 fresh device framebuffer captures**, fictional test pets and injected ADC | All images reviewed; no real player readings published |
| Normal restoration | After gallery capture, normal firmware reported LIVE, `test_mode: false`, and healthy game/collection saves | Roster, all eight existing history entries, sensitivity and collected/equipped items matched private before/after snapshots |

Firmware v8 changes a confirmed new evening into a complete game-progress reset, including clothes, colours and shared decorations. The 105-check suite ran on the board with isolated saves; both firmware environments were built, and normal firmware was restored after gallery capture. Private serial reports and normal snapshots remain in ignored local artifacts.

## Automated coverage

The suite drives the actual navigation handlers and checks:

- Adoption, unique nicknames, capacity, menu selections, owner isolation and confirmation before clearing an evening.
- Five seconds of GET READY followed by ten seconds of BLOW, excluding countdown exposure from the peak.
- Background rolling baselines, immediate Feed, queued recovery, cancellation, explicit retry after invalid input and sample-count/voltage rejection.
- Source labeling and original sensor metadata, calibration/history persistence, malformed commands and animation progress.
- Zero-response wakeups, no high-score damage, DROWSY/ASLEEP boundaries, mini-game misses and three-catch wins.
- Reward cooldowns, cup/hat rewards, wardrobe, shared upgrades, awards, returning-name colours and collection persistence.

Test saves use `breath-test` and `fun-test`; normal saves use `breath-pet` and `pet-fun`. Synthetic ADC, accelerated time and bubble-position controls exist only in test firmware. Normal firmware previously rejected the test-only time and bubble commands. The test and gallery helpers attempt to restore normal firmware even after a failure; a disconnected board still needs reconnection and a successful upload.

## Screen verification

The [gallery](docs/screenshots/README.md) replaces screenshots from earlier interfaces. It covers adoption, tank states, pet belongings, wardrobe, bubble catch, countdown, capture, result/history, recovery, menu, sensitivity, bench diagnostics, awards, upgrades and new-evening confirmation. Every selectable page uses the same physical-button rail and gold action bar. The pet page has one energy meter; tank labels show each pet's state.

These are **rendered framebuffer exports**, not photos or physical panel readback. The TEST badge identifies isolated firmware. Even when an image says MQ3, the gallery's sensor input is injected; it is not a human reading. [The manifest](docs/screenshots/manifest.json) records the capture date, firmware version, source revision and binary/image hashes. Original source for this capture is commit `cf34876`.

## Persistence

The current save layout stores party/history data and collection/progress data separately. An earlier low-space condition in the 20 KB NVS partition was fixed by removing only obsolete `party-v1` after a valid `party-v2` record is loaded. Existing v2 pets/history were preserved; no full NVS erase was performed. Save health, restart behavior and collection persistence passed subsequent checks.

The gallery utility compares normal saved fields and exact histories before and after flashing its fixture, without copying private readings into public documentation. A confirmed new evening clears all nickname collections, equipped items, shared upgrades and their progress, as well as the roster and history. Normal restarts retain them; device sensitivity settings survive an evening reset.

## Physical limits and next checks

The planned assembly uses 5 V module power, common ground and two 8 kΩ resistor chains between AO, GPIO1 and GND. **Divider voltages have not been independently verified with a meter.** See the [wiring checks](MQ3_WIRING.md#verify-the-divider).

Earlier cup testing observed approximately 107 mV in clean air, 414 mV during exposure to sake vapor and 106 mV after removal. Subsequent live feeding also recorded higher responses and stored the original baseline/peak values. This supports qualitative response, recovery and persistence, not a calibrated alcohol measurement.

The current full five-plus-ten-second workflow was checked with injected ADC values. A fresh user-operated physical cup capture through that complete workflow remains to be checked. The physical background-readiness tests above were deliberately cancelled before sampling. A completed quiet capture is accepted by design, and the MQ-3 cannot prove airflow or identify who supplied a sample. Touch hardware, battery-powered sensor operation, long-duration sensor stability and BAC accuracy are not verified.

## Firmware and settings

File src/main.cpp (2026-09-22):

#include <Arduino.h>
#include <TFT_eSPI.h>
#include <Wire.h>
#include <math.h>
#include <ModulesCSTSelf.tpp>
#include <ModulesCSTMutual.tpp>
#include "party.h"
#include "mq3.h"
#include "fun.h"

constexpr int POWER_PIN=15,BACKLIGHT_PIN=38;
TFT_eSPI lcd;
TFT_eSprite frame(&lcd);
PartyStorage storage;
FunStorage fun;
Mq3Monitor mq3;
SensorFeed sensorFeed;
bool inputLive=!BREATH_PET_TEST_MODE;
bool feedPending=false;
uint32_t responseId=0;
TouchLibCSTSelf selfTouch(Wire,18,17,0x15,21);
TouchLibCSTMutual mutualTouch(Wire,18,17,0x1A,21);
TouchLibInterface *touch=nullptr;
const char *touchName="none";
bool displayReady=false;
uint32_t frames=0,touchTaps=0,carePresses=0,samplePresses=0;
uint32_t lastTick=0,lastFrame=0,lastStatus=0,samplingStart=0;
uint32_t fedAt[MAX_PLAYERS]={},restedAt[MAX_PLAYERS]={};
bool fed[MAX_PLAYERS]={},rested[MAX_PLAYERS]={};
enum Page {TANK,NAME_PICK,PET_PICK,PET,FEED,SAMPLING,RESULT,HISTORY,MENU,CALIBRATION,NEW_NIGHT,SENSOR,WARDROBE,PLAY,AWARDS,DECOR,COUNTDOWN};
const char *const PAGE_NAMES[]={"tank","name","choose_pet","pet","feed","sampling","result","history","menu","calibration","new_night","sensor","wardrobe","play","awards","decor","countdown"};
Page page=TANK;
int cursor=6,selected=-1,joiningSlot=-1,nameIndex=0,petIndex=0,historyPage=0;
int demoIndex=1,lastRaw=0,resultDelta=0;
const int DEMO_VALUES[]={0,25,50,85};
const char *notice="";
uint32_t noticeAt=0;
int catches=0;
#if BREATH_PET_TEST_MODE
int bubbleOverride=-1;
#endif
int bubblePosition(uint32_t now) {
#if BREATH_PET_TEST_MODE
  if(bubbleOverride>=0) return bubbleOverride;
#endif
  int p=(now/18)%200; return p<=100?p:200-p;
}

void status(bool waitForSpace=false);
void message(const char *text);
void tap(int x,int y);
#include "hardware.h"

bool hasPlayer() { return selected>=0 && selected<MAX_PLAYERS && storage.data.players[selected].active; }
Player &player() { return storage.data.players[selected]; }
void show(Page next) {
  if((page==SAMPLING || page==COUNTDOWN) && next!=SAMPLING && next!=COUNTDOWN) sensorFeed.cancel();
  // Live input keeps a rolling clean-air window on every screen.
  if(inputLive || next==SENSOR) { if(!mq3.active) mq3.begin(millis()); }
  else mq3.active=false;
  if(next!=FEED) feedPending=false;
  page=next; cursor=0; notice="";
  if(next==PLAY) catches=0;
  if (next==TANK) {
    cursor=6;
    for (int i=0;i<MAX_PLAYERS;i++) if (storage.data.players[i].active) { cursor=i; break; }
  }
}
bool tankTarget(int i) { return i==7 || (i==6?storage.count()<MAX_PLAYERS:storage.data.players[i].active); }
void addPet() {
  for (int i=0;i<MAX_PLAYERS;i++) if (!storage.data.players[i].active) {
    joiningSlot=i; nameIndex=0;
    while (storage.nameUsed(PICKER_NAMES[nameIndex])) nameIndex=(nameIndex+1)%NAME_COUNT;
    petIndex=i%PET_TYPES; show(NAME_PICK); return;
  }
  message("TANK FULL: SIX PETS TONIGHT");
}
void message(const char *text) { notice=text; noticeAt=millis(); }
uint32_t cooldown(int slot) {
  if (!fed[slot]) return 0;
  uint32_t elapsed=millis()-fedAt[slot];
  return elapsed<FEED_COOLDOWN_MS?FEED_COOLDOWN_MS-elapsed:0;
}
void newNight() {
  storage.newNight(); fun.sync(storage.data); selected=-1; joiningSlot=-1;
  memset(fed,0,sizeof(fed)); memset(rested,0,sizeof(rested));
  memset(fedAt,0,sizeof(fedAt)); memset(restedAt,0,sizeof(restedAt));
  lastRaw=0; resultDelta=0; catches=0; historyPage=0;
  lastTick=millis(); show(TANK);
}
bool capture(int raw) {
  if (inputLive || !hasPlayer() || raw<0 || raw>100 || cooldown(selected)) return false;
  lastRaw=raw; resultDelta=storage.record(selected,raw,millis());
  fun.wake(selected,player().lastScore,millis(),esp_random());
  fed[selected]=true; fedAt[selected]=millis(); show(RESULT); return true;
}
void beginFeed() {
  if (!hasPlayer()) return;
  if (cooldown(selected)) { message("PET IS FULL. WAIT A MOMENT."); return; }
  if(inputLive && !sensorFeed.start(mq3,millis())) return;
  samplingStart=millis(); show(COUNTDOWN);
}
void finishLiveFeed() {
  if(!sensorFeed.valid()) { show(FEED); message("NO READING SAVED: CHECK SIGNAL"); return; }
  int raw=sensorScore(sensorFeed.baseline,sensorFeed.peak,storage.data.sensorSpanMv);
  resultDelta=storage.record(selected,raw,millis(),1,sensorFeed.baseline,sensorFeed.peak);
  fun.wake(selected,player().lastScore,millis(),esp_random());
  fed[selected]=true; fedAt[selected]=millis(); show(RESULT);
}
void restPet() {
  if (!hasPlayer()) return;
  if (rested[selected] && millis()-restedAt[selected]<10000) { message("RESTING... TRY AGAIN SOON."); return; }
  storage.rest(selected); rested[selected]=true; restedAt[selected]=millis(); fun.nap(selected); message("NAP TIME / PLAY OR FEED TO WAKE");
}
void calibrate(int action) {
  if(inputLive) {
    if(action==0) storage.data.sensorSpanMv=max(100,int(storage.data.sensorSpanMv)-100);
    if(action==1) storage.data.sensorSpanMv=min(2000,int(storage.data.sensorSpanMv)+100);
    if(action==2) storage.data.sensorSpanMv=MQ3_DEFAULT_SPAN_MV;
    if(action==3) { show(MENU); return; }
    storage.save(); return;
  }
  if (action==0) storage.data.zero=lastRaw;
  if (action==1) { storage.data.zero=0; storage.data.span=100; }
  if (action==2) storage.data.span=max(25,int(storage.data.span)-25);
  if (action==3) storage.data.span=min(200,int(storage.data.span)+25);
  storage.save();
}
void nextName() {
  do { nameIndex=(nameIndex+1)%NAME_COUNT; } while (storage.nameUsed(PICKER_NAMES[nameIndex]));
}
void selectSlot(int slot) {
  if (slot<0 || slot>=MAX_PLAYERS) return;
  if (storage.data.players[slot].active) { selected=slot; show(PET); }
  else {
    joiningSlot=slot; nameIndex=0;
    if (storage.nameUsed(PICKER_NAMES[nameIndex])) nextName();
    petIndex=slot%PET_TYPES; show(NAME_PICK);
  }
}
void back() {
  if (page==NAME_PICK || page==PET || page==MENU || page==NEW_NIGHT) show(TANK);
  else if (page==PET_PICK) show(NAME_PICK);
  else if (page==CALIBRATION || page==SENSOR || page==AWARDS || page==DECOR) show(MENU);
  else if (page==TANK) show(MENU);
  else if (hasPlayer()) show(PET);
  else show(TANK);
}
void next() {
  notice="";
  switch (page) {
    case TANK: do { cursor=(cursor+1)%8; } while (!tankTarget(cursor)); break;
    case NAME_PICK: nextName(); break;
    case PET_PICK: petIndex=(petIndex+1)%PET_TYPES; break;
    case PET: cursor=(cursor+1)%5; break;
    case FEED: if(!inputLive) demoIndex=(demoIndex+1)%4; break;
    case RESULT: cursor=1-cursor; break;
    case HISTORY: historyPage=(historyPage+1)%max(1,(int(player().count)+2)/3); break;
    case MENU: cursor=(cursor+1)%7; break;
    case SENSOR: cursor=(cursor+1)%3; break;
    case CALIBRATION: cursor=(cursor+1)%4; break;
    case NEW_NIGHT: cursor=1-cursor; break;
    case WARDROBE: cursor=(cursor+1)%4; break;
    case PLAY: cursor=1-cursor; break;
    case AWARDS: cursor=(cursor+1)%3; break;
    case DECOR: cursor=(cursor+1)%3; break;
    case COUNTDOWN: case SAMPLING: break;
  }
}
void activate() {
  notice="";
  switch (page) {
    case TANK: if (cursor==7) show(MENU); else if (cursor==6) addPet(); else selectSlot(cursor); break;
    case NAME_PICK: show(PET_PICK); break;
    case PET_PICK: {
      int slot=storage.join(PICKER_NAMES[nameIndex],petIndex,joiningSlot);
      if (slot>=0) { fun.sync(storage.data); selected=slot; show(PET); } else message("NAME TAKEN OR TANK FULL");
      break;
    }
    case PET:
      if (cursor==0) { show(FEED); if(inputLive) { feedPending=true; mq3.poll(millis()); beginFeed(); } }
      else if (cursor==1) { historyPage=0; show(HISTORY); }
      else if(cursor==2) restPet();
      else if(cursor==3) show(WARDROBE);
      else show(PLAY);
      break;
    case FEED:
      if(inputLive && feedPending) show(PET);
      else { feedPending=inputLive; beginFeed(); }
      break;
    case RESULT: show(cursor==0?TANK:PET); break;
    case HISTORY: show(PET); break;
    case MENU:
      if (cursor==0) show(TANK); else if (cursor==1) show(CALIBRATION); else if (cursor==2) show(NEW_NIGHT); else if(cursor==3) show(SENSOR);
      else if(cursor==5) show(AWARDS);
      else if(cursor==6) show(DECOR);
      else { inputLive=!inputLive; message(inputLive?"LIVE MQ-3 FEEDING ENABLED":"DEMO FEEDING ENABLED"); }
      break;
    case SENSOR:
      if (cursor==2) show(MENU);
      else if (cursor==1) { mq3.hasBaseline=false; message("BASELINE CLEARED"); }
      else if (mq3.zero()) message("TEMPORARY AIR BASELINE SET");
      else message("WAIT FOR A QUIET, VALID SIGNAL");
      break;
    case CALIBRATION: calibrate(cursor); break;
    case NEW_NIGHT: if (cursor==1) newNight(); else show(MENU); break;
    case WARDROBE: if(cursor==3) show(PET); else fun.dress(selected,cursor); break;
    case PLAY:
      if(cursor) { show(PET); break; }
      if(abs(bubblePosition(millis())-50)<=18) {
        if(++catches>=3) { fun.play(selected,millis(),esp_random()); show(PET); message("THREE CATCHES / HELLO AGAIN!"); }
        else message("POP! CATCH THE NEXT ONE");
      } else message("MISSED / TRY AGAIN");
      break;
    case AWARDS: case DECOR: show(MENU); break;
    case COUNTDOWN: case SAMPLING: break;
  }
}

void swimPosition(int slot,uint32_t now,int &x,int &y) {
  const auto &f=fun.data.pets[slot];
  if(f.idle>=20) { x=80+slot*39; y=116; return; }
  float speed=f.idle>=10?130.0f:f.vibe>=70?29.0f:f.vibe>=25?48.0f:70.0f;
  float phase=fmodf(now/speed+slot*71.0f,408.0f);
  x=82+int(phase<=204?phase:408-phase);
  y=70+(slot%2)*35+int(sinf(now/(f.vibe>=70?220.0f:1300.0f)+slot*1.8f)*(f.vibe>=70?10:7));
  // Shared, short scenes gather awake pets without confining them to boxes.
  if(now%24000<4500) {
    if(f.personality==3) { x=92+int((now%4500)/27); y=78; }
    else { x=75+slot*37+int(sinf(now/330.0f+slot)*9); y=94; }
  }
}
void tap(int x,int y) {
  if (x<0 || x>=320 || y<0 || y>=170) return;
  if (x<47) { if (y<85) next(); else activate(); }
  else if (y>=139) activate();
  else if (page==TANK) {
    if (y>=32 && y<139) {
      int closest=-1,distance=1600;
      for (int i=0;i<MAX_PLAYERS;i++) if (storage.data.players[i].active) {
        int px,py; swimPosition(i,millis(),px,py); int d=(x-px)*(x-px)+(y-py)*(y-py);
        if (d<distance) { distance=d; closest=i; }
      }
      if (closest>=0) selectSlot(closest);
    }
  } else if (page!=SAMPLING && page!=COUNTDOWN) next();
  status();
}

#include "ui.h"

void status(bool waitForSpace) {
  uint32_t started=millis();
  while(Serial.availableForWrite()<2048) {
    if(!waitForSpace || millis()-started>=500) return;
    delay(1);
  }
  char record[2048];
  size_t length=snprintf(record,sizeof(record),"{\"app\":\"breath-pet\",\"version\":8,\"sensor\":\"%s\",\"page\":\"%s\",\"cursor\":%d,\"selected\":%d,\"players\":%d,\"night\":%lu,\"boot\":%lu,\"zero\":%u,\"span\":%u,\"display\":%s,\"psram\":%u,\"frames\":%lu,\"uptime_ms\":%lu,\"touch\":\"%s\",\"touch_taps\":%lu,\"care_presses\":%lu,\"sample_presses\":%lu,\"storage_ok\":%s,\"demo_raw\":%d,\"picker_name\":\"%s\",\"picker_pet\":%d,\"cooldown_ms\":%lu",
    inputLive?"MQ3":"SIMULATED",PAGE_NAMES[page],cursor,selected,storage.count(),(unsigned long)storage.data.night,
    (unsigned long)storage.data.boot,storage.data.zero,storage.data.span,displayReady?"true":"false",
    ESP.getPsramSize(),(unsigned long)frames,(unsigned long)millis(),touchName,(unsigned long)touchTaps,
    (unsigned long)carePresses,(unsigned long)samplePresses,storage.lastWriteOK?"true":"false",
    DEMO_VALUES[demoIndex],PICKER_NAMES[nameIndex],petIndex,(unsigned long)(hasPlayer()?cooldown(selected):0));
  if (hasPlayer()) length+=snprintf(record+length,sizeof(record)-length,",\"name\":\"%s\",\"pet_type\":%u,\"health\":%u,\"food\":%u,\"joy\":%u,\"score\":%u,\"feeds\":%lu,\"history_count\":%u,\"mood\":\"%s\"",
    player().name,player().type,player().health,player().food,player().joy,player().lastScore,
    (unsigned long)player().feeds,player().count,mood(player()));
  if(hasPlayer()) {
    const auto &f=fun.data.pets[selected]; const auto *c=fun.collection(player().name,false);
    length+=snprintf(record+length,sizeof(record)-length,",\"energy\":%d,\"state\":\"%s\",\"idle_minutes\":%u,\"checkins\":%u,\"naps\":%u,\"games\":%u,\"encounters\":%u,\"hat\":%u,\"item\":%u,\"colour\":%u,\"hats\":%u,\"items\":%u,\"colours\":%u,\"visits\":%u,\"reward_ready\":%s,\"loot\":%d",
      fun.energy(selected),fun.state(selected),f.idle,f.checkins,f.naps,f.games,f.encounters,c?c->hat:0,c?c->item:0,c?c->colour:0,c?c->hats:1,c?c->items:1,c?c->colours:1,c?c->visits:0,fun.rewardReady(selected)?"true":"false",fun.lastLoot);
  }
  length+=snprintf(record+length,sizeof(record)-length,",\"fun_storage_ok\":%s,\"upgrades\":%u,\"catches\":%d",fun.lastWriteOK?"true":"false",fun.data.upgrades,catches);
  length+=snprintf(record+length,sizeof(record)-length,",\"test_mode\":%s,\"mq3_active\":%s,\"mq3_mv\":%d,\"mq3_adc\":%d,\"mq3_samples\":%lu,\"mq3_spread_mv\":%d,\"mq3_can_zero\":%s,\"mq3_baseline_mv\":%d",
    BREATH_PET_TEST_MODE?"true":"false",mq3.active?"true":"false",mq3.millivolts,mq3.raw,(unsigned long)mq3.samples,mq3.spread(),mq3.canZero()?"true":"false",mq3.hasBaseline?mq3.baseline:-1);
  length+=snprintf(record+length,sizeof(record)-length,",\"feed_ready\":%s,\"feed_baseline_mv\":%d,\"feed_peak_mv\":%d,\"sensor_span_mv\":%u,\"recovering\":%s,\"request_id\":%lu}\n",
    (inputLive && page!=COUNTDOWN && page!=SAMPLING && sensorFeed.ready(mq3))?"true":"false",sensorFeed.baseline,sensorFeed.peak,storage.data.sensorSpanMv,sensorFeed.recovered(mq3)?"false":"true",(unsigned long)responseId);
  // Small writes also handle the hardware USB CDC ring buffer wrapping.
  size_t offset=0; uint32_t progress=millis();
  while(offset<length) {
    size_t n=Serial.write(reinterpret_cast<const uint8_t *>(record)+offset,min(size_t(256),length-offset));
    offset+=n;
    if(n) progress=millis();
    else if(millis()-progress>=500) break;
    delay(1);
  }
}
void historyStatus() {
  if (!hasPlayer()) { Serial.println("ERROR select a pet first"); return; }
  Serial.printf("{\"request_id\":%lu,\"owner\":\"%s\",\"history\":[",(unsigned long)responseId,player().name);
  for (int i=0;i<player().count;i++) {
    const Sample &r=player().readings[i];
    Serial.printf("%s{\"n\":%lu,\"boot\":%lu,\"seconds\":%lu,\"raw\":%u,\"score\":%u,\"health_delta\":%d,\"source\":\"%s\",\"baseline_mv\":%u,\"peak_mv\":%u,\"span_mv\":%u}",i?",":"",
      (unsigned long)r.number,(unsigned long)r.boot,(unsigned long)r.seconds,r.raw,r.score,r.healthDelta,r.source?"MQ3":"DEMO",r.baselineMv,r.peakMv,r.spanMv);
  }
  Serial.println("]}");
}
void selfTest() {
  Player p; bool ok=true;
  feedPlayer(p,0); ok &= p.food==85 && p.health==100;
  p=Player(); feedPlayer(p,25); Player q; feedPlayer(q,69);
  ok &= p.food==q.food && p.joy==q.joy;
  feedPlayer(p,85); ok &= p.health==100;
  for (int i=0;i<30;i++) feedPlayer(p,100);
  ok &= p.health==100 && p.joy==100 && p.food==100;
  ok &= gameScore(20,45,100)==0 && gameScore(85,45,25)==100;
  static const PartyData freshParty;
  static const LegacyPartyData freshLegacy;
  static PartyStorage scratch; scratch.data=freshParty;
  int first=scratch.join("CAPTAIN",0),second=scratch.join("GOOSE",1);
  ok &= first==0 && second==1 && scratch.join("CAPTAIN",2)==-1;
  for (int i=0;i<20;i++) scratch.record(first,i,1000+i);
  ok &= scratch.data.players[first].count==16 && scratch.data.players[first].readings[0].raw==19;
  ok &= scratch.data.players[first].readings[15].raw==4 && scratch.data.players[second].count==0;
  ok &= storage.valid(storage.data) && displayReady && ESP.getPsramSize()>8000000;
  Mq3Monitor bench; bench.active=true;
  for(int i=0;i<99;i++) bench.ingest(1000,1300);
  ok &= !bench.zero(); bench.ingest(1020,1320);
  ok &= bench.zero() && bench.baseline==1000;
  bench.ingest(1500,1900); ok &= !bench.canZero();
  for(int i=0;i<100;i++) bench.ingest(0,0);
  ok &= !bench.canZero();
  for(int i=0;i<100;i++) bench.ingest(2900,4000);
  ok &= !bench.canZero();
  static LegacyPartyData old; old=freshLegacy; old.boot=4; old.zero=12; old.span=75;
  strcpy(old.players[0].name,"CAPTAIN"); old.players[0].active=1; old.players[0].feeds=1; old.players[0].count=1;
  old.players[0].readings[0].raw=25; old.players[0].readings[0].number=7;
  static PartyData migrated; migrated=PartyStorage::migrate(old);
  ok &= storage.valid(migrated) && migrated.boot==4 && migrated.zero==12 && migrated.span==75;
  ok &= !strcmp(migrated.players[0].name,"CAPTAIN") && migrated.players[0].readings[0].number==7 && !migrated.players[0].readings[0].source;
  bench=Mq3Monitor(); bench.active=true; SensorFeed trial;
  for(int i=0;i<99;i++) bench.ingest(100,100);
  ok &= !trial.start(bench,1000); bench.ingest(100,100);
  ok &= trial.start(bench,1000);
  for(int i=0;i<100;i++) trial.accept(400);
  ok &= trial.valid() && !trial.done(10999) && trial.done(11000) && trial.peak==400;
  ok &= sensorScore(100,399,1200)==0 && sensorScore(100,400,1200)==23 && sensorScore(139,852,1200)==57 && sensorScore(139,999,1200)==70 && sensorScore(100,2700,1200)==100;
  trial.cancel(); for(int i=0;i<100;i++) bench.ingest(400,400);
  ok &= !trial.ready(bench); for(int i=0;i<100;i++) bench.ingest(110,110);
  ok &= trial.start(bench,20000); trial.accept(0); ok &= trial.invalid && !trial.valid();
  // Clean-air boundaries apply even before the first feed; a stable plume is rejected.
  trial=SensorFeed(); bench=Mq3Monitor(); bench.active=true;
  for(int i=0;i<100;i++) bench.ingest(250,300);
  ok &= trial.ready(bench); bench.ingest(251,301); ok &= !trial.ready(bench);
  for(int i=0;i<100;i++) bench.ingest(400,500);
  ok &= !trial.ready(bench);
  for(int i=0;i<100;i++) bench.ingest(200,250);
  ok &= trial.start(bench,30000); trial.cancel();
  for(int i=0;i<100;i++) bench.ingest(250,300);
  ok &= trial.ready(bench) && trial.recovered(bench);
  scratch.record(second,23,2000,1,100,400);
  const Sample &measured=scratch.data.players[second].readings[0];
  ok &= measured.source==1 && measured.score==23 && measured.baselineMv==100 && measured.peakMv==400 && measured.spanMv==1200;
  static FunStorage wardrobe;
  static const FunData freshFun;
  wardrobe.data=freshFun; wardrobe.sync(scratch.data);
  wardrobe.wake(first,0,1000,0); // First check-in: cup.
  wardrobe.data.minutes+=10;
  wardrobe.wake(first,0,2000,8); // Five hats + three other items precede colours.
  auto *outfit=wardrobe.collection("CAPTAIN",false);
  ok &= outfit && outfit->colours==3 && outfit->colour==1 && wardrobe.lastLoot==21;
  wardrobe.sync(scratch.data); // Same evening, as on reboot: preserve rewards.
  ok &= wardrobe.data.totalRewards==2 && wardrobe.collection("CAPTAIN",false)->colours==3;
  scratch.newNight(); wardrobe.sync(scratch.data);
  ok &= wardrobe.data.minutes==0 && wardrobe.data.totalRewards==0 && !wardrobe.data.upgrades;
  ok &= !wardrobe.collection("CAPTAIN",false) && !wardrobe.collection("GOOSE",false);
  ok &= !wardrobe.celebrating && !wardrobe.lastLoot && !wardrobe.wakeAt[first];
  Serial.printf("SELFTEST %s game rules, stat bounds, calibration, sensor baseline guards, saved schema, framebuffer, PSRAM\n",ok?"PASS":"FAIL");
}
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
void loop() {
  uint32_t now=millis();
  int a=careButton.poll(now),b=sampleButton.poll(now);
  pollTouch(now);
  if (a) { ++carePresses; if (a==2) back(); else next(); status(); }
  if (b) { ++samplePresses; if (b==2) show(MENU); else activate(); status(); }
  static String input; static bool overflow=false;
  int budget=64;
  while (Serial.available() && budget-->0) {
    char c=Serial.read();
    if (c=='\n') {
      input.trim(); responseId=0;
      if(input.startsWith("@")) {
        int space=input.indexOf(' ');
        if(space>1 && space<=10) {
          bool digits=true; for(int i=1;i<space;i++) digits &= isDigit(input[i]);
          if(digits) { responseId=strtoul(input.substring(1,space).c_str(),nullptr,10); input=input.substring(space+1); }
        }
      }
      if(responseId) Serial.printf("CMD %lu\n",(unsigned long)responseId);
      else Serial.println("CMD");
      if (overflow) Serial.println("ERROR command too long");
      else { input.trim(); if (input.length()) command(input); }
      input=""; overflow=false;
      responseId=0;
    } else if (c!='\r') { if (input.length()<64) input+=c; else overflow=true; }
  }
  now=millis(); // Commands may reset timers or take time (e.g. screenshot).
  if(inputLive || page==SENSOR) { if(!mq3.active) mq3.begin(now); }
  else mq3.active=false;
  bool sampled=mq3.poll(now);
  if(page==FEED && feedPending && sensorFeed.ready(mq3) && !cooldown(selected)) {
    beginFeed(); now=millis(); // beginFeed resets samplingStart; avoid unsigned timer underflow.
  }
  if(page==COUNTDOWN && now-samplingStart>=5000) {
    samplingStart=now; sensorFeed.started=now; show(SAMPLING);
  }
  if(page==SAMPLING && inputLive) {
    if(sampled) sensorFeed.accept(mq3.millivolts);
    if(sensorFeed.invalid || sensorFeed.done(now)) finishLiveFeed();
  } else if (page==SAMPLING && now-samplingStart>=10000) capture(DEMO_VALUES[demoIndex]);
  if (now-lastTick>=60000) { lastTick+=60000; storage.tick(); fun.tick(); }
  if (displayReady && now-lastFrame>=80) { lastFrame=now; draw(now); }
  if (now-lastStatus>=5000) { lastStatus=now; status(); }
  delay(2);
}

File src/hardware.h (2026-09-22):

#pragma once

struct Button {
  int pin; bool raw = HIGH, stable = HIGH, held = false;
  uint32_t changed = 0, pressed = 0;
  explicit Button(int gpio) : pin(gpio) {}
  // Returns a tap on release or a single hold event after 1.2 seconds.
  int poll(uint32_t now) {
    bool value = digitalRead(pin);
    if (value != raw) { raw = value; changed = now; }
    int event = 0;
    if (now - changed >= 30 && stable != raw) {
      stable = raw;
      if (!stable) { pressed = now; held = false; }
      else if (!held) event = 1;
    }
    if (!stable && !held && now - pressed >= 1200) { held = true; event = 2; }
    return event;
  }
};
Button careButton{0}, sampleButton{14};

// Updated panel initialization from LILYGO's official tft example.
struct LcdCommand { uint8_t cmd, data[14], len; };
const LcdCommand panelCommands[] = {
  {0x11,{0},0x80}, {0x3A,{0x05},1}, {0xB2,{0x0B,0x0B,0,0x33,0x33},5},
  {0xB7,{0x75},1}, {0xBB,{0x28},1}, {0xC0,{0x2C},1}, {0xC2,{1},1},
  {0xC3,{0x1F},1}, {0xC6,{0x13},1}, {0xD0,{0xA7},1},
  {0xD0,{0xA4,0xA1},2}, {0xD6,{0xA1},1},
  {0xE0,{0xF0,0x05,0x0A,0x06,0x06,0x03,0x2B,0x32,0x43,0x36,0x11,0x10,0x2B,0x32},14},
  {0xE1,{0xF0,0x08,0x0C,0x0B,0x09,0x24,0x2B,0x22,0x43,0x38,0x15,0x16,0x2F,0x37},14}
};

void initTouch() {
  touch=nullptr; touchName="none";
  gpio_hold_dis(GPIO_NUM_21);
  pinMode(21,OUTPUT); digitalWrite(21,LOW); delay(500); digitalWrite(21,HIGH); delay(50);
  pinMode(16,INPUT_PULLUP); Wire.begin(18,17); Wire.setTimeOut(20);
  Wire.beginTransmission(0x15);
  if (Wire.endTransmission()==0 && selfTouch.init()) { touch=&selfTouch; touchName="CST816-family"; selfTouch.setRotation(1); }
  else {
    Wire.beginTransmission(0x1A);
    if (Wire.endTransmission()==0 && mutualTouch.init()) { touch=&mutualTouch; touchName="CST328"; mutualTouch.setRotation(1); }
  }
}

void pollTouch(uint32_t now) {
  static uint32_t lastPoll=0, lastSeen=0;
  static bool down=false;
  if (!touch || now-lastPoll<15) return;
  lastPoll=now;
  bool pressed=touch->read() && touch->getPointNum()>0;
  if (pressed) {
    TP_Point p=touch->getPoint(0);
    if (!down) { ++touchTaps; Serial.printf("TOUCH %u %u\n",p.x,p.y); tap(p.x,p.y); }
    down=true; lastSeen=now;
  } else if (now-lastSeen>90) down=false;
}

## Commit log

2026-09-22 Build ESP32 virtual pet with simulated readings and persistent calibration
2026-09-22 Document MQ-3 divider using available 2k resistors
2026-09-22 Align pet interface with physical buttons and isolate device tests
2026-09-22 Unify menu selection and add isolated MQ-3 voltage bench test
2026-09-22 Refresh project guides and capture current firmware screen gallery
2026-09-22 Add direct MQ-3 carrier PCB and printable prototype enclosure
    [carrier-B_Cu.gbl, carrier-B_Mask.gbs, carrier-B_Silkscreen.gbo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]
2026-09-22 Reset all game progress when starting a new evening
    [capture_gallery.py, main.cpp, test_device.py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]
2026-09-22 Record 105 device checks and refresh v8 screen gallery
2026-09-22 Flag first carrier layout for measured sensor sizing revision
2026-09-22 Resize carrier and case around measured MQ-3 sensor
    [carrier-B_Cu.gbl, carrier-B_Mask.gbs, carrier-B_Silkscreen.gbo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]
2026-09-22 Remove custom carrier sensor board and enclosure project
    [carrier-B_Cu.gbl, carrier-B_Mask.gbs, carrier-B_Silkscreen.gbo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]
